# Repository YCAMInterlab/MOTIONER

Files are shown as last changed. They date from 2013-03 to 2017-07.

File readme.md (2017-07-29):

# MOTIONER

## Open source low cost inertial motion capture system.



MOTIONER is a low cost inertial motion capture system developed for Reactor for Awareness in Motion(RAM) project at Yamaguchi Center for Arts in Media (YCAM). Using MOTIONER, you can capture, record and playback body movements, and send the data via OSC messages over a network. MOTIONER is designed to work with RAM Dance Toolkit using openFrameworks, and will work with creative coding environments that provide OSC. MOTIONER is developed in collaboration with Yoko Ando (The Forsythe Company) and other dancers. MOTIONER is a light weight, low-stress, and low latency system. Because it's an inertial system, the sensors can be attached either inside or on the outside of clothing.

For more details, please see [MOTIONER wiki](https://github.com/YCAMInterlab/MOTIONER/wiki/)

詳しい情報は[MOTIONER wiki](https://github.com/YCAMInterlab/MOTIONER/wiki/)を参照してください。

## Licenses

### Application
MOTIONER software by YCAM InterLab and Yoshito Onishi is licensed under the 
[Apache License, Version2.0](http://www.apache.org/licenses/LICENSE-2.0.html)

    Copyright 2012-2013 YCAMInterLab and Yoshito Onishi

    Licensed under the Apache License, Version 2.0 (the "License");
    you may not use this file except in compliance with the License.
    You may obtain a copy of the License at

       http://www.apache.org/licenses/LICENSE-2.0

    Unless required by applicable law or agreed to in writing, software
    distributed under the License is distributed on an "AS IS" BASIS,
    WITHOUT WARRANTIES OR CONDITIONS OF ANY KIND, either express or implied.
    See the License for the specific language governing permissions and
    limitations under the License.

### Arduino, Processing sketch and mbed code

Copyright 2012-2013 YCAMInterLab and Yoshito Onishi

MOTIONER Arduino, Processing sketch and mbed code by YCAM InterLab and Yoshito Onishi are licensed under the 
[GNU GPL(General Public License) v3.0](http://www.gnu.org/licenses/gpl.html)

### Hardware

<br /><span xmlns:dct="http://purl.org/dc/terms/" property="dct:title">MOTIONER hardware related documents (Schematics, Eagle files, Solder Stencil Mask, Drawing of MOTIONER base, MOTIONER pcb board, vacuum case and strap)</span> by <a xmlns:cc="http://creativecommons.org/ns#" href="http://interlab.ycam.jp/projects/ram" property="cc:attributionName" rel="cc:attributionURL">YCAM InterLab, Yoshito Onishi</a> is licensed under a <a rel="license" href="http://creativecommons.org/licenses/by-sa/4.0/">Creative Commons Attribution-ShareAlike 4.0 International License</a>.

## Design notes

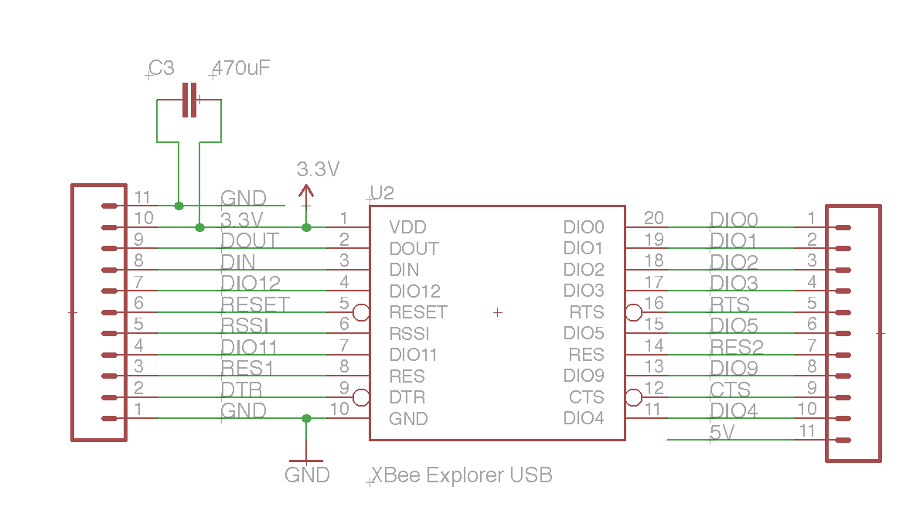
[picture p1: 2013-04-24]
circuit/schematics/xbee_explorer.png

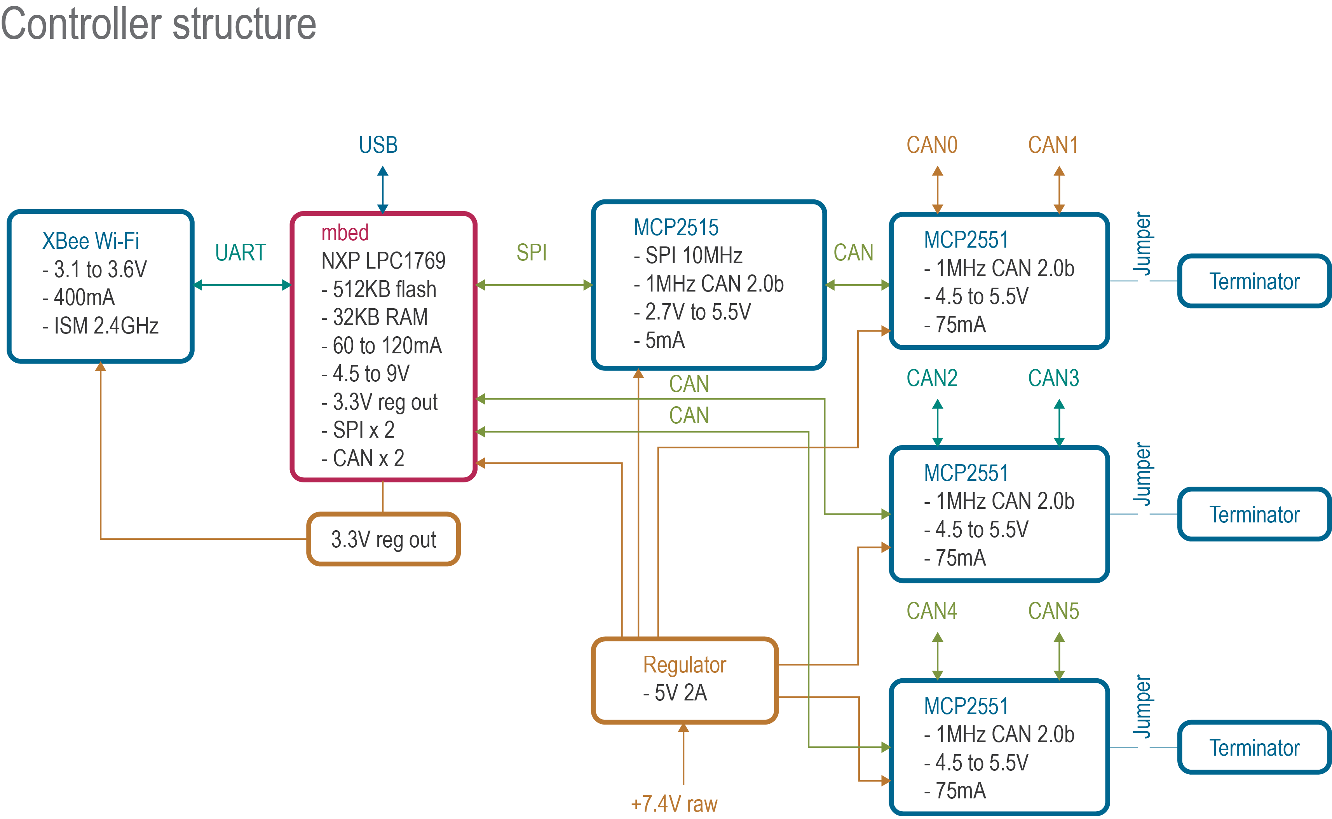
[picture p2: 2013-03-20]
documents/png/Controller-diagram.png

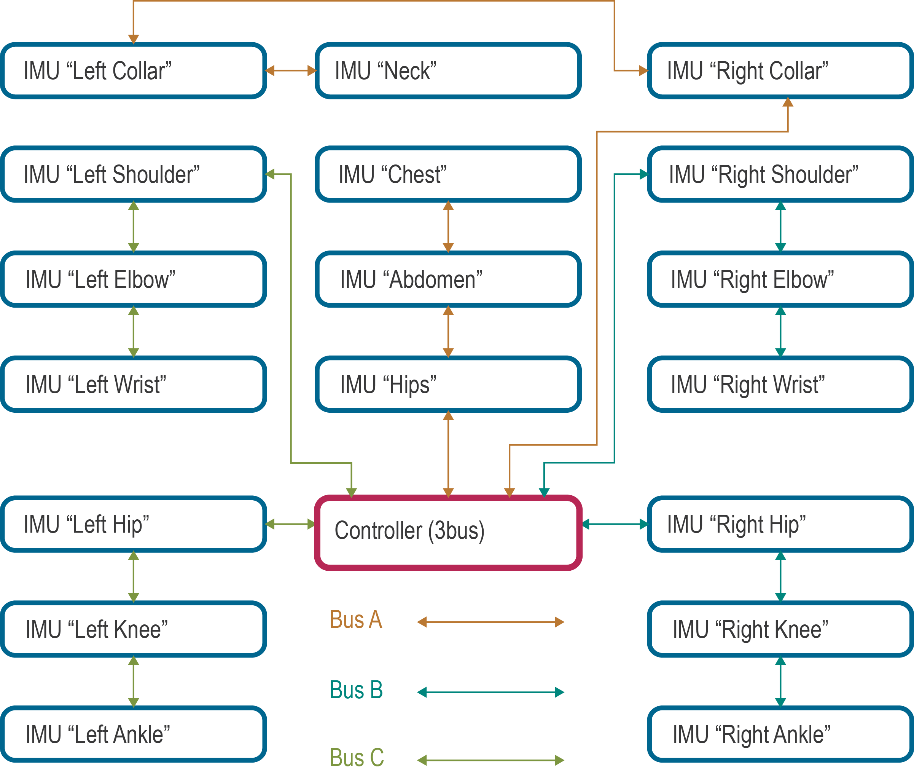
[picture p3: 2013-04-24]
documents/ai/CAN bus diagram.png

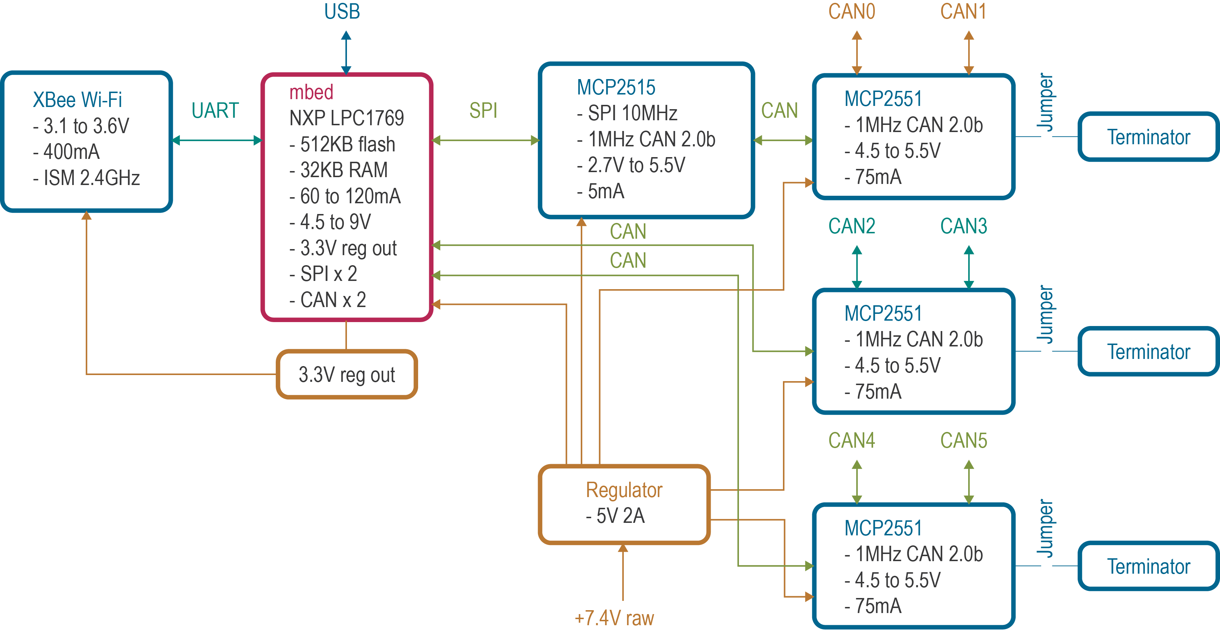
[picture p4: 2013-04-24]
documents/ai/Controller diagram.png

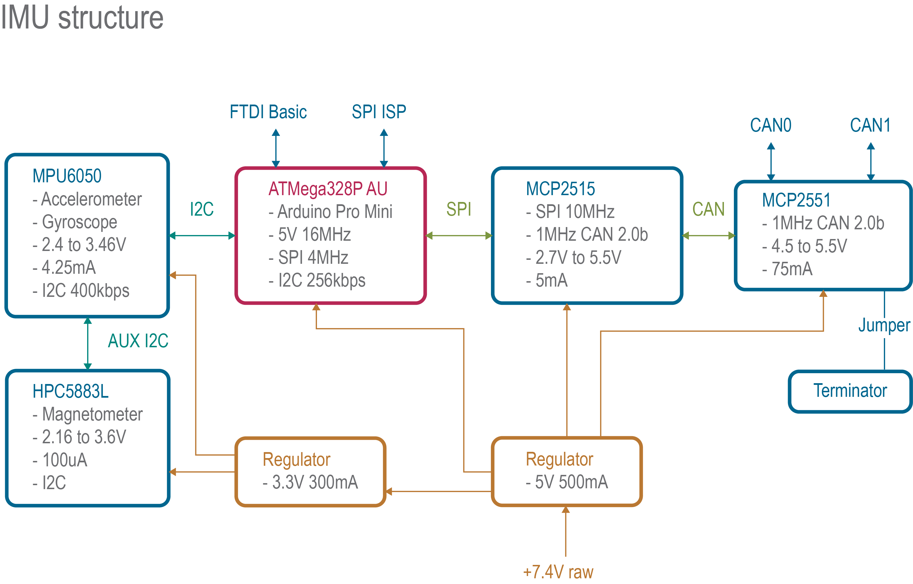
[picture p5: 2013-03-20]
documents/png/IMU-diagram.png

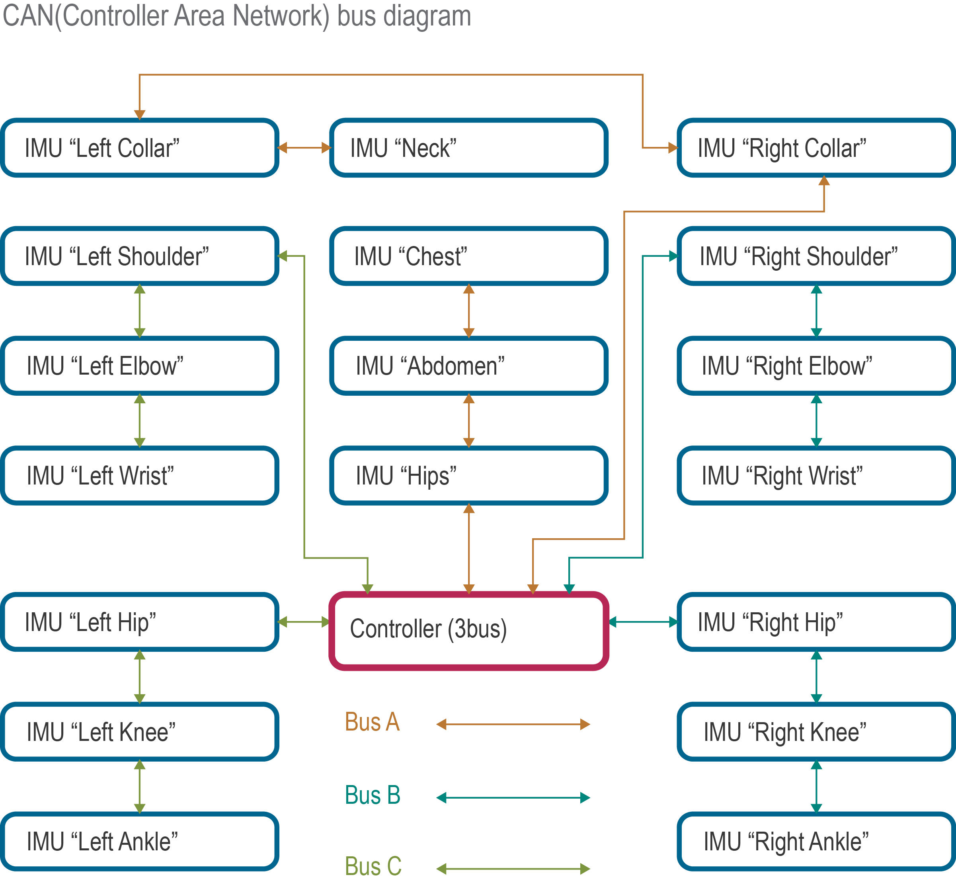
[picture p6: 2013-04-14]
documents/png/CAN-bus-diagram.png

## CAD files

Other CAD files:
circuit/stencil/dxf/MotionerNode-tcream.dxf

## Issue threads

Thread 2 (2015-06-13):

Things to fix in the wiki

jtragtenberg, 2015-06-13:
Hello,
I am making my Motioner sensors and I noticed some small mistakes in the wiki:

in the tutorial showing how to use the Arduino UNO as an ISP programmer, the frizzing image tells you have to put the capacitor between the 5V and the Reset... that is dangerous... it missed one hole, its between GND and Reset.

Another mistake is in the parts list, it says that for the IMU that the 10kOhm resistors are the R5-9, while they are only from R5 to R8.

And another thing I noticed is that the mbed code is the only one missing in the github. You only put the binary, and I really want to understand what is going on and maybe improve it a bit if I can. Can you please put it there?

One last thing: You added a calibration process in the making tutorial but forgot to put the referred folder in gitHub: "Open the MOTIONER/Arduino/calibration folder and open calibrationServo.ino"... there is no calibration folder there...

thanks a lot!
Amazing project!

I'm eager to contribute to it as much as I can!

jtragtenberg, 2015-06-13:
Another mistake in the parts:
C9 isn't a 0.1 uF capacitor as listed in the 0.1uF IMU parts list

itotaka, 2015-06-15:
> the frizzing image tells you have to put the capacitor between the 5V and the Reset... that is dangerous... it missed one hole, its between GND and Reset.

It's fixed. Thank you!

> Another mistake is in the parts list, it says that for the IMU that the 10kOhm resistors are the R5-9, while they are only from R5 to R8.

Fixed.

> And another thing I noticed is that the mbed code is the only one missing in the github. You only put the binary, and I really want to understand what is going on and maybe improve it a bit if I can. Can you please put it there?

Sorry, I'm checking this right now, wait for a bit.

> One last thing: You added a calibration process in the making tutorial but forgot to put the referred folder in gitHub: "Open the MOTIONER/Arduino/calibration folder and open calibrationServo.ino"... there is no calibration folder there...

Fixed, Please check here again.
https://github.com/YCAMInterlab/MOTIONER/wiki/Make-MOTIONER-IMU-and-Controller

> C9 isn't a 0.1 uF capacitor as listed in the 0.1uF IMU parts list

Fixed.

Thanks!!!!

jtragtenberg, 2015-06-15:
Thanks Takayuki!

just noticed one other thing: the controller battery connectors aren't in the buying list either.
I noticed you used in the picture two lipoly batteries and on the buying list you chose the 6 AA battery pack instead, but since I prefer the lipoly, I put the connectors there. The problem was that I put a 90˚ model of the connector, and the only way it fit was with the opposite polarity... Only after almost burning my board I read the eagle file and noticed the right polarity.
It would be nice to add to the parts list a straight jst connector and the barrel connectors too.

Thank you!

Here is a video of my first working IMU. Haven't calibrated them yet and is already very good!
https://youtu.be/LNvjPWxWtFw

I am planning on making an app for mapping the gestures from motioner to sound, I'll send you my updates!

jtragtenberg, 2015-06-15:
You could also put in the buying list the servo motor and mdf boards for calibration...
And you could put as an alternative to the Silhouete for cutting the solder stencils a laser cutter. I made mine with these and they have worked great!

itotaka, 2015-06-16:
Here's MOTIONER mbed code, the place will be changed.
For now, please use this mbed repository.

https://developer.mbed.org/users/FalconOnishi/code/MotionerController/

and yes, we chose 6AA battery pack when we published, since Lipo battery is sometimes a bit dangerous. But maybe it's good to add description for who wanna use it.

> Here is a video of my first working IMU. Haven't calibrated them yet and is already very good!

Thanks for sharing your video.
it's really good to see it's working at your place!!

> You could also put in the buying list the servo motor and mdf boards for calibration...
> And you could put as an alternative to the Silhouete for cutting the solder stencils a laser cutter. I made mine with these and they have worked great!

Great! We'd love to add these.
Thanks, it's very helpful!!

jtragtenberg, 2015-06-19:
One other thing, Ito
I just realized that one of the components isn't specified in the buying list. The XBee Wifi has two models, the S6 and a new version: S6B. I bought the second one and just realized from the picture that you used S6. They seem to be compatible, but I don't know if the mbed code has to change at all.
All the configurations from S6 configuration file can be set on the S6B. There are, though some 20 configuration items that are new in this version that don't seem to make much of a change.

Since my board isn't sending any OSC messages (I checked with the motioner app as well as with PureData and also with OSC data monitor) I don't know if the problem is in the Controller Board, in the mbed code or in the XBee itself. There seems to be something going a lot wrong since the voltage regulator and the CAN controller are heating up a lot! After some seconds the four mbed leds 1 and 4 start blinking alternately with the leds 2 and 3, which is a mbed code error alert. I checked the voltage in all the power elements, and the 5v for mbed and 3.3v for xbee are fine.

Since I've never used mbed or xbee wifi before its taking a lot to understend the mbed code, but I hope I find a way to fix this problem.

Can it be a problem that I'm using only one IMU sensor to test? Does the mbed code break if all the sensors aren't connected? That wouldn't make sense, and the code doesn't seem to have anything like that. I want to, at first, use only 3 IMUs to monitor just one arm, so I just bought enough components to make these 3. Hope I can make them work soon...

It would be nice to specify in the list you used XBee Wifi S6

Thank you!

XianWorld, 2015-10-23:
I have read all the three codes of IMU, Controller and Motion App, the message from IMU is include velocity and the control message is 'q':

```c++
void MotionerIMU::updateCAN()
{
    switch (getCANControlMessage()) {
    
        case 0: break; /// no message
    
        case 'q':
            //Serial.println("StartTransfer");
            digitalWrite(LED, HIGH);
            sendCANDataQuaternion();
            sendCANDataAux();
            digitalWrite(LED, LOW);
            break;
    
        default: break;
    }
}
```

But Controller only read the quaternion and send it to Motioner App:

```c++
                // 0to18 Joints and RX buffer*2(quaternion xy or zw) and 8 byte CAN data
                if (nodeId < N_JOINTS && slot < 2 && msg.len == 8) {
                    //gPc.printf("%x, %x\n\r", nodeId, slot);

                    for (int q=0; q<2; q++) { //quaternion x, y or z, w
                        for (int f=0; f<4; f++) { //float byte 0 - 4
                            //[node id][quaternion x, y or z, w][float bytes 0 - 4]
                            gTmpQuat[nodeId][q+slot*2].b[f] = msg.data[f+q*4];
                        }
                    }
                }
```
And I don't understand why did you add the position vector to the data length, but not send anything of it:

```C++
#define N_JOINTS (18)
#define DATA_LEN (4*4*N_JOINTS+3*4+4) //18*quaternion*float bytes + position vector*flot bytes + delimiter
```
```C++
void updateXBeeWiFi()
{
    IPv4TransmitRequest data;

    //XBee WiFi Transmit
    //IPv4TransmitRequest data;
    //int len = 2*4*18+2*3; //18*quaternion+3*vector q // short
    //int len = 4*4*18+4*3; //18*quaternion+3*vector // float
    //int len = 8; //18*quaternion+3*vector // float
    //char buf[len];

    // debug
    //for (int i=0; i<len; i++)
    //buf[i] = (char)('0'+i%70);

    for (int i=0; i<N_JOINTS; i++) {
        if (gReceived[i][0] && gReceived[i][1]) {
            for (int j=0; j<4; j++) {
                __gQuat__[i][j] = gTmpQuat[i][j].f;
            }
        }
    }

    uint8_t *buf = (uint8_t *)__gQuat__;

    buf[DATA_LEN-4] = (char)'a';
    buf[DATA_LEN-3] = (char)'b';
    buf[DATA_LEN-2] = (char)'c';
    buf[DATA_LEN-1] = (char)'d';

    IpAddr addr(192, 168, 2, 1);
    data.setAddress(addr);
    data.setDstPort(9750);
    data.setSrcPort(9750);
    data.setProtocol(PROTOCOL_UDP);
    //data.setPayload((uint8_t*)buf);
    //data.setPayloadLength(strlen(buf));
    data.setPayload(buf);
    data.setPayloadLength(DATA_LEN);
    data.setFrameId(gXBee.getNextFrameId());//0
    gXBee.send(data);

    //gPc.printf("len:%d\r\n",strlen(buf));
    const int r = gXBee.getWiResponse(TX_STATUS_RESPONSE, data.getFrameId());

    /// error
    if (r==-1) {
        gPc.printf("Fatal error! XBee WiFi didn't responce!\r\nTrying to reset modem again.");
        if (initXBeeWiFi(20)) {
            gPc.printf("Failure...");
            error("");
        } else {
            gPc.printf("succeed\r\n");
        }
    }
}
```

And the CAN control message send from Controller to IMU is 'b' and 'e', not 'q':

```C++
void beginTransmitQuaternion()
{
    sendCanMessage('b');
    for (int i=0; i<N_MBED_CAN; i++)
        sendMbedCanMessage(i, 'b');
}

//--------------------------------------------------------------
void endTransmitQuaternion()
{
    sendCanMessage('e');
    for (int i=0; i<N_MBED_CAN; i++)
        sendMbedCanMessage(i, 'e');
}
```

And the Motioner App read velocity from the message sent from Controller:

```C++
    const int    FLOAT_BYTES = 4;
    const int    QUATERNION_DIM = 4;
    const int    IMU_DATA_DIM = 5;
    const int    UDP_MESSAGE_LENGTH = IMU_DATA_DIM*FLOAT_BYTES*(NUM_JOINTS-N_END_SITE)+4;
    const string UDP_PACKET_DELIMITER = "abcd";
```

```C++
            for (int j=0; j<IMU_DATA_DIM; j++) { /// quaternion xyzw + velocity
                for (int k=0; k<FLOAT_BYTES; k++) { /// float bytes
                    /// i*4*5 + i*4 + k
                    const int idx =
                    (i-nEndSite)*IMU_DATA_DIM*FLOAT_BYTES + j*FLOAT_BYTES+k;
                    mData[i][j].b[k] = udpMessage[idx];
                }
                //if (ofGetFrameNum()%60==0)
                //    cout << mData[i][j].f << ",";
            }
            //if (ofGetFrameNum()%60==0)
            //    cout << endl;

            /// get velocity
            if (mData[i][4].f!=0.0f) {
                //cout << i << ":" << mData[i][4].f << endl;
                frame.velocity.at(i) = mData[i][4].f;
            }
```

According to all above, I judge that [the code of Controller from mbed](https://developer.mbed.org/users/FalconOnishi/code/MotionerController/) is old(or testing) version.

Please check it, thank you.

We are making the Motioner system according to your way, and now debug each parts together.

XianWorld, 2015-10-25:
The Controller code is old version, would you pls upload new version.

Thx a lot.

gongyuzhen, 2017-02-09:
The new version？

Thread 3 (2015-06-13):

Improving the IMU board

jtragtenberg, 2015-06-13:
The soldering pads for the HMC5883L are too small. I would make it as long outside of the chip just a little bit like the ones from MPU6050, that way it is easier to check if all the pads were correctly soldered, and it makes it possible to fix the soldering with a soldering iron.

I can improve it, how do I upload to this git my changes?

kylemcdonald, 2015-06-22:
since you've forked the repository, once you make the changes to the file you can do this:

```
$ git add -u # this stages changes to any files already added to git
$ git commit -m "made the soldering pads for the HMC5883L bigger" # this saves any staged changes
$ git push origin master # this sends your commit to the server
```

then on github there will be a button that appears that allows you to make a pull request, and we can merge it.

jtragtenberg, 2015-07-21:
Thanks Kyle,
Just learned how to use eagle and git to do this, just requested a pull.

kylemcdonald, 2015-07-23:
closed by #7

Closed 2015-07-23.

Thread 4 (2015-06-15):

How did you get position?

jtragtenberg, 2015-06-15:
I am reading you code and still I couldn't figure out how you managed to get the position on stage from the actors using only joint angles...
Do you use any other external sensors like cameras or a kinect?

thanks!

itotaka, 2015-06-16:
No, sorry, currently MOTIONER doesn't get absolute positions of joints, body.
Once we tried to combine a camera or Kinects with it, but still need some developments..

jtragtenberg, 2015-06-16:
Then how did you do the videos you published where the avatars move around in space?
All the videos you have that happens, and is only possible if you have the position captured. If you got just relative positions the avatar would move as if it was in a slippery floor, no?

itotaka, 2015-06-16:
There're 2 possibilities.

1. We borrowed an optical motion capture system for experiments. Some of the videos and sample data are from them.
2. MOTIONER application simulates walking roughly by fixing the lowest joint position. The data from MOTIONER sensors itself is, yes, slippery on the floor.

mmmmm, I'm sorry for your confusion, I'll add the description about this.

jtragtenberg, 2015-06-16:
Great, that was what I was looking for.
I beleive videos like https://vimeo.com/61942488 show the dancers reacting with each other wearing motioners, so its probably the second alternative.
Is this lowest joint position fixing done in RAM Dance Toolkit? The OSC data sent from the mbed is only the quaternions of each joint?

And I sent you an email to taka@ycam.jp, is that your email?
beacause I'm researching on my masters how to create music from dance, and my plans are to use motioner to generate music. I would like to know more about the RAM project, and about YCAM for my research.
could I send you some questions about the process?
Could you pass me the email of the other people involved in this project so I could interview them too?

my email is tragtenberg@gmail.com

Thank you!

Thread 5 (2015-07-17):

WIFI setting and network problems

sworldy, 2015-07-17:
Hi all,

  You guys' work is very amazing. I am also attempting to build a device just like that in the tutorial.
    I use Xbee S6B wifi module and have encountered the network connection problem, as a result, I cant see the unfixed Skeleton. I set up all the 18 imu motioners and 1 controller just like the demo shown. And all the settings are correct as shown in the tutorial. I am wondering the reasons for the connection error, whether setting up the wrong communication protocol or the software/code problem.
   I also tried to connect XBee to PC through gateway. However, the data received from wifi S6b was just something like FF 00 E8 FF which was obviously wrong.
   Based on my understanding, I would like to ask you guys some questions.

1.	From the tutorial, the IP address for PC or motioner application is 192.168.2.1; controller IP address is 192.168.2.103; the wifi S6 module IP address is 192.168.2.7 and the destination IP address is 192.168.2.1; the motioner application target IP address is 192.168.2.103.
My puzzle is about the connection between wifi S6 / S6B and PC application. From the user manual, one’s MY is set to be the DL of another and another’s MY is referred to one’s DL. My question is the target IP setting of the motioner application, the target IP address is referred to the controller IP address instead of the wifi S6 module IP. Is the data sent out by wifi S6/S6B module with controller IP address as the destination address for motioner application?
 2.  In the application gui xml file, Device Incoming UDP Port means UDP protocol used while the wifi S6 configuration, IP setting is TCP protocol. My question is whether these two protocols are compatible to be used together?
3.  In XBee WiFi_setting file, ID SSID name is set as "f" while the network created in the tutorial, the SSID name is named as "MotionerNet". Are these two SSID names supposed to be the same? If not, how will XBee identify the network?

If anything wrong, please do not hesitate to correct me.
Please help me clear my doubts. Thank you guys in advance.

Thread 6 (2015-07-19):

Problems in Magnetometer Calibration

jtragtenberg, 2015-07-19:
Hello,
I have just bought the servo and cut the wood to calibrate my IMUs.
My calibration went fine with the accelerometer and gyroscope (I hope so), at least I could visualize the colored lines and dots move as I moved my IMU. The problem was when I started calibrating the magnetometer. I had it all set up with the servo but when I ran the processing sketch the green dot didn't leave the center of the sphere. And I tried to upload this only-dotted-calibration-data to my motioner IMU and it failed with this message:

It seems like a bug in the sketch.
Can someone help me?

java.lang.RuntimeException: java.lang.RuntimeException: Eigenvalue Decomposition failed
	at com.jogamp.common.util.awt.AWTEDTExecutor.invoke(AWTEDTExecutor.java:58)
	at jogamp.opengl.awt.AWTThreadingPlugin.invokeOnOpenGLThread(AWTThreadingPlugin.java:103)
	at jogamp.opengl.ThreadingImpl.invokeOnOpenGLThread(ThreadingImpl.java:206)
	at javax.media.opengl.Threading.invokeOnOpenGLThread(Threading.java:172)
	at javax.media.opengl.Threading.invoke(Threading.java:191)
	at javax.media.opengl.awt.GLCanvas.display(GLCanvas.java:541)
	at processing.opengl.PJOGL.requestDraw(PJOGL.java:688)
	at processing.opengl.PGraphicsOpenGL.requestDraw(PGraphicsOpenGL.java:1651)
	at processing.core.PApplet.run(PApplet.java:2256)
	at java.lang.Thread.run(Thread.java:745)
Caused by: java.lang.RuntimeException: Eigenvalue Decomposition failed
	at org.ejml.simple.SimpleEVD.<init>(Unknown Source)
	at org.ejml.simple.SimpleBase.eig(Unknown Source)
	at MagnCalibration.outputMagnCalibration(MagnCalibration.java:430)
	at MagnCalibration.keyPressed(MagnCalibration.java:300)
	at processing.core.PApplet.keyPressed(PApplet.java:3510)
	at processing.core.PApplet.handleKeyEvent(PApplet.java:3328)
	at processing.core.PApplet.dequeueEvents(PApplet.java:2728)
	at processing.core.PApplet.handleDraw(PApplet.java:2397)
	at processing.opengl.PJOGL$PGLListener.display(PJOGL.java:862)
	at jogamp.opengl.GLDrawableHelper.displayImpl(GLDrawableHelper.java:665)
	at jogamp.opengl.GLDrawableHelper.display(GLDrawableHelper.java:649)
	at javax.media.opengl.awt.GLCanvas$10.run(GLCanvas.java:1289)
	at jogamp.opengl.GLDrawableHelper.invokeGLImpl(GLDrawableHelper.java:1119)
	at jogamp.opengl.GLDrawableHelper.invokeGL(GLDrawableHelper.java:994)
	at javax.media.opengl.awt.GLCanvas$11.run(GLCanvas.java:1300)
	at java.awt.event.InvocationEvent.dispatch(InvocationEvent.java:302)
	at java.awt.EventQueue.dispatchEventImpl(EventQueue.java:733)
	at java.awt.EventQueue.access$200(EventQueue.java:103)
	at java.awt.EventQueue$3.run(EventQueue.java:694)
	at java.awt.EventQueue$3.run(EventQueue.java:692)
	at java.security.AccessController.doPrivileged(Native Method)
	at java.security.ProtectionDomain$1.doIntersectionPrivilege(ProtectionDomain.java:76)
	at java.awt.EventQueue.dispatchEvent(EventQueue.java:703)
	at java.awt.EventDispatchThread.pumpOneEventForFilters(EventDispatchThread.java:242)
	at java.awt.EventDispatchThread.pumpEventsForFilter(EventDispatchThread.java:161)
	at java.awt.EventDispatchThread.pumpEventsForHierarchy(EventDispatchThread.java:150)
	at java.awt.EventDispatchThread.pumpEvents(EventDispatchThread.java:146)
	at java.awt.EventDispatchThread.pumpEvents(EventDispatchThread.java:138)
	at java.awt.EventDispatchThread.run(EventDispatchThread.java:91)

jtragtenberg, 2015-07-19:
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

here is what I saw in the MagnCalibration sketch

jtragtenberg, 2015-07-19:
And just to check, are these images ok for the accelerometer and gyroscope calibration?

It is said on the wiki that there would be some examples of good calibration I believe you forgot to upload it.

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

jtragtenberg, 2015-07-19:
It seems it was a problem with the hardware itself...
I have just calibrated the magnetometer of another board and it seems perfect:
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

jtragtenberg, 2015-07-19:
I tried swapping the magnetometer in the board, desoldered the last one and soldered a new one. But the RAW data kept coming with null values for magnetometer readings. from the 9 numbers that come one after the other the 3 accelerometer and 3 gyroscope values are fine. Just the magnetometer values keep coming with zeros...

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

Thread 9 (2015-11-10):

Bug in the calcQuaternion algorithm

jtragtenberg, 2015-11-10:
Hi there,
I've been all this time learning C++ and figuring out how the Motioner and RazorIMU libraries work.
I make my own prototyping board with just an arduino UNO soldered with a HMC8553L magnetometer and MPU6050 gyro+accel. I'm doing all my tests connecting the board through USB.
I made a code out of the Motioner.ino where in the loop() I just added the lines:

  float qx = motioner.mRazorIMU.getQuatX();
  float qy = motioner.mRazorIMU.getQuatY();
  float qz = motioner.mRazorIMU.getQuatZ();
  float qw = motioner.mRazorIMU.getQuatW();

  Serial.print(qw);
  Serial.print('|');
  Serial.print(qx);
  Serial.print('|');
  Serial.print(qy);
  Serial.print('|');
  Serial.println(qz);

where the getQuat* functions I added are just:

    float getQuatX() const { return quat.x; }
    float getQuatY() const { return quat.y; }
    float getQuatZ() const { return quat.z; }
    float getQuatW() const { return quat.w; }

and I made the mRazorIMU object public on the Motioner class.

Out of this I noticed a bug in the angles as I tilt them, where the quaternions change sign for no reason...
I have calibrated my board with the IMUDebug.ino firmware and it all worked well in the IMUvisualization Processing sketch.

Does anyone know why this bug keeps bugging me?
Is this discontinuity and sign inversion expected?

thank you

jtragtenberg, 2015-11-19:
Anyone?...

jtragtenberg, 2015-11-19:
Has anyone an example of a Motioner IMU working just outputting the quaternion values ?
It really seems to me that the bug is in the calcQuaternion algorithm, the Gamasutra code that transforms the Matrix into quats....

skistua, 2015-12-15:
you are right . It's wrong. Give me your email address . then I send your  right one . it's project is long gone. Here is no one answer your question.

jtragtenberg, 2015-12-15:
Hi there,

 its joao@batebit.cc

Thank you

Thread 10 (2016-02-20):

jxx_315 questions

jtragtenberg, 2016-02-20:
jxx_315 has sent me an email asking these things:

hi, my friend:
   I am an electronics enthusiast, recently in the understanding of motion capture projects. A few days ago I saw your message in MOTIONER project. I would like to know what is wrong wtih the code, can  you give me the correct code? thanks.
I have several questions:
1. "How did you get position?" This seems to be a serious problem, you have any good way to get position?
2: The Controller code is old version, do you have new version?

jtragtenberg, 2016-02-20:
Hey jxx_315, I'll answer you here:

1: to get a position from an inertial motion capture you have to work hard (; The IMU sensors only give you orientation values, that is, angles! With this angles and estimating the size of each body limb you can organize many vectors and estimate the position in relation to the persons body center. To get an estimation of the position of someone walking you have to fix the lower part of the body... complicated huh? I heard there is also an algorithm to help predicting displacement in jump, but I haven't got a clue how that is done...

2: The controller code is in mbed, do you have it? They didn't put it the source on github, its only in the mbed platform. The link to it is: https://developer.mbed.org/users/FalconOnishi/code/MotionerController/

What have you managed to do so far?

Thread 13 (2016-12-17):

How to select electronic components in the project

mobilemajia, 2016-12-17:
Dear Takayuki,

Good day! The motioner project is a great well designed project :) I am an electronic fan and I learnt this project is a happy journey!

I found a problem when I tried to start building the project. It seems that some electronic components obsolete when I want to buy them. One of them is "XBee Wi-Fi" in the buying list in the following links:

888-XB24-WFPIT-001:
http://www.mouser.jp/ProductDetail/Digi-International/XB24-WFPIT-001/?qs=sGAEpiMZZMtbbFRYSpBbW17OwPV%252b3FUq

It is not available now. Do you know where to buy it? Or is there another choice?

I find two alternative components is alike it, but I don't know how to choose the right one. I don't know which component will be good for motioner. Could you please help me to choose one? If it is good, do I need to change the code in order to adapt to the new electronic components? Thank you so much.

The main difference among these two components with the original one is the "data rate", "interface type", "aerial connector type".

Two alternative components:

888-XB2B-WFPS-001:
http://www.mouser.cn/Search/ProductDetail.aspx?qs=NnxJOTDiCpMA4dfbwsXxnw%3d%3d

888-XB2B-WFST-001
http://www.mouser.cn/Search/ProductDetail.aspx?qs=NnxJOTDiCpM4EnkS2FAtgw%3d%3d

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

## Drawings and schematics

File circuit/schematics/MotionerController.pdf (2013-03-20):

VREF 5 | GND VCC
VREF 5 | GND VCC

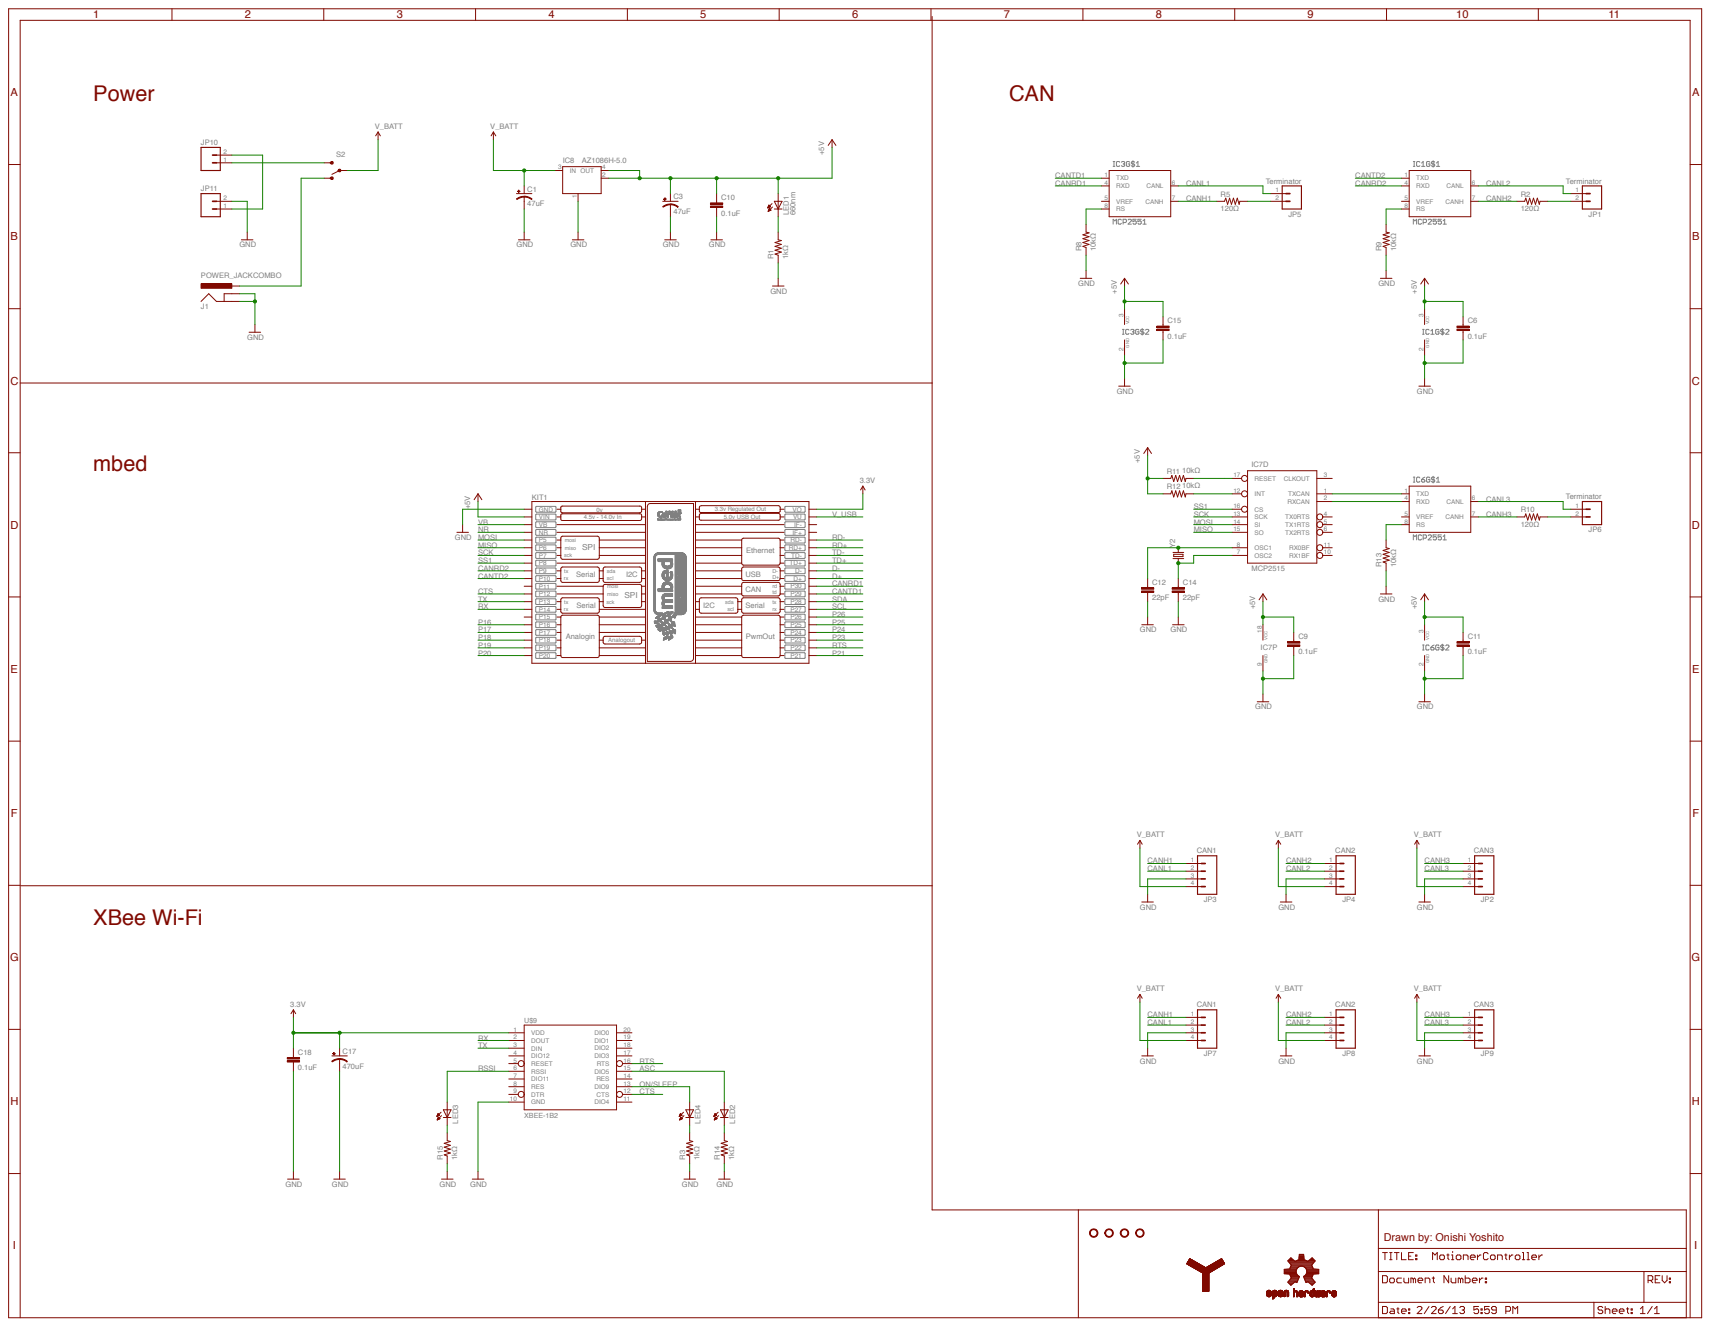
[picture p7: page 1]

Drawn by: Onishi Yoshito

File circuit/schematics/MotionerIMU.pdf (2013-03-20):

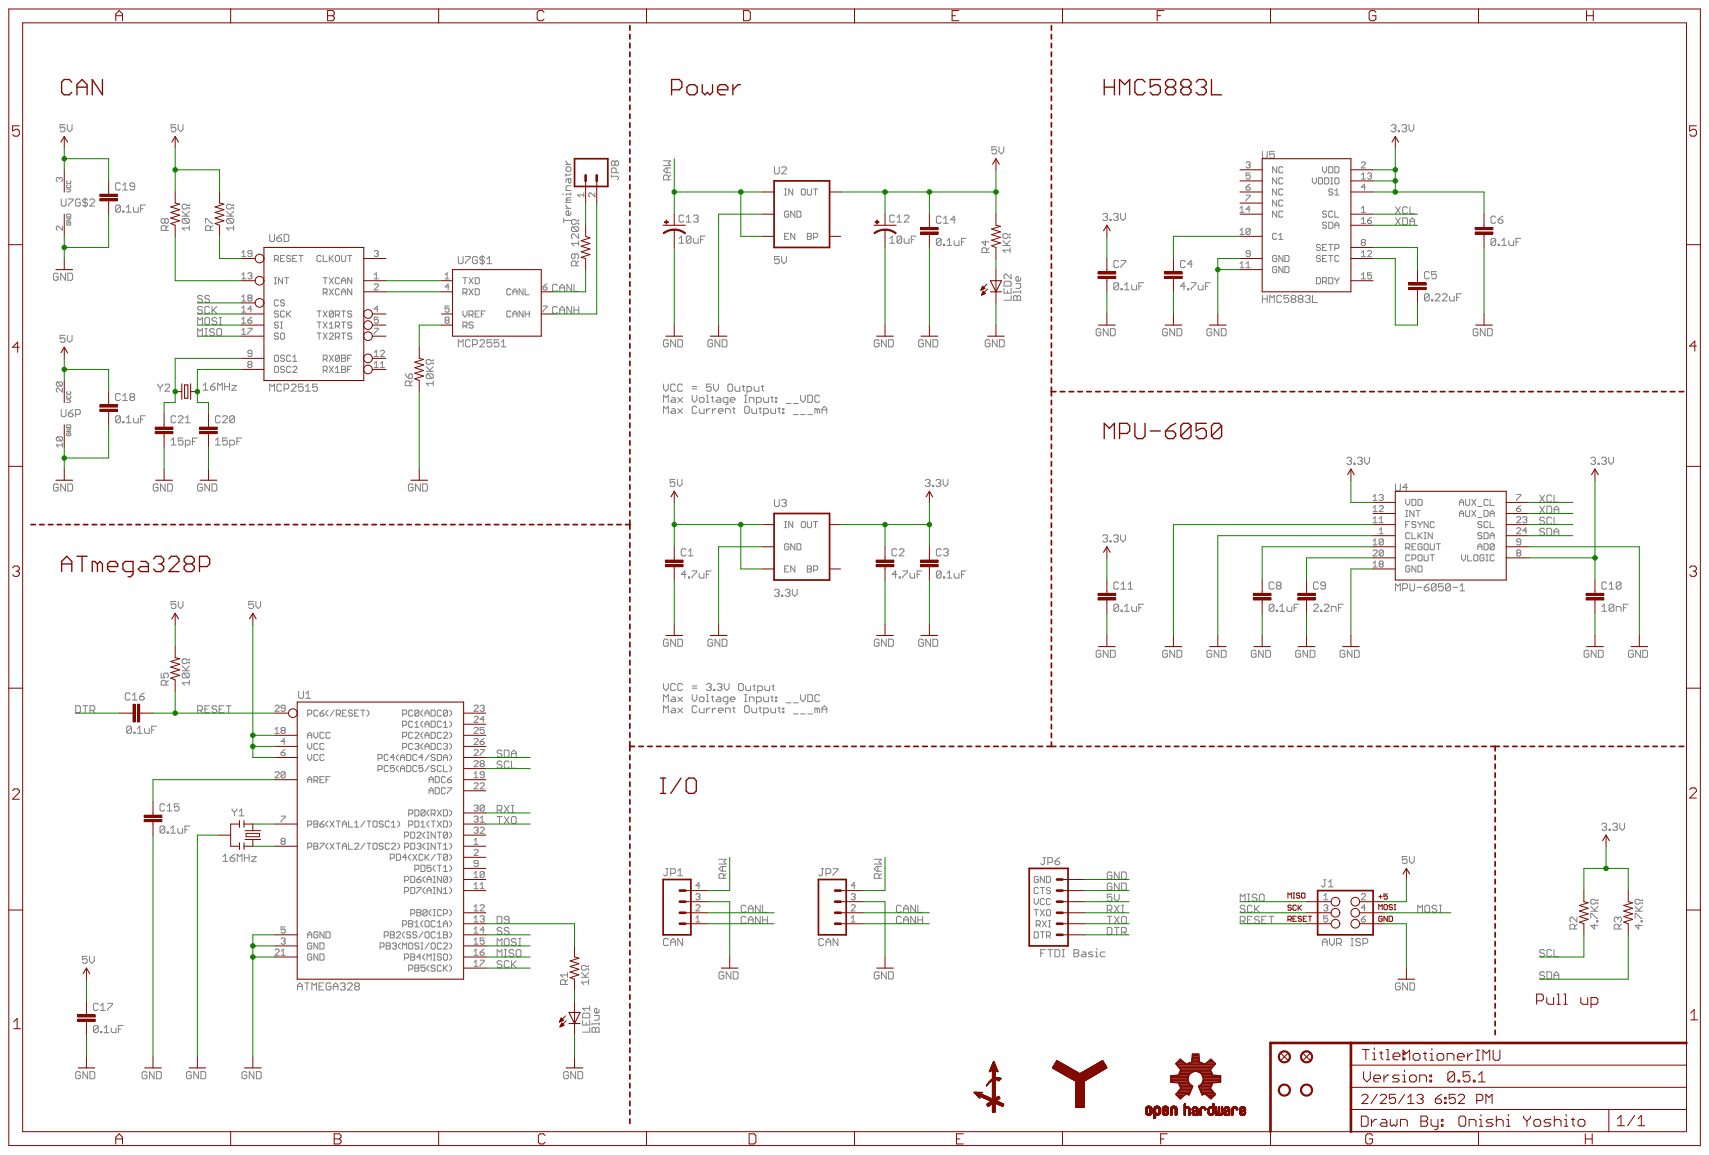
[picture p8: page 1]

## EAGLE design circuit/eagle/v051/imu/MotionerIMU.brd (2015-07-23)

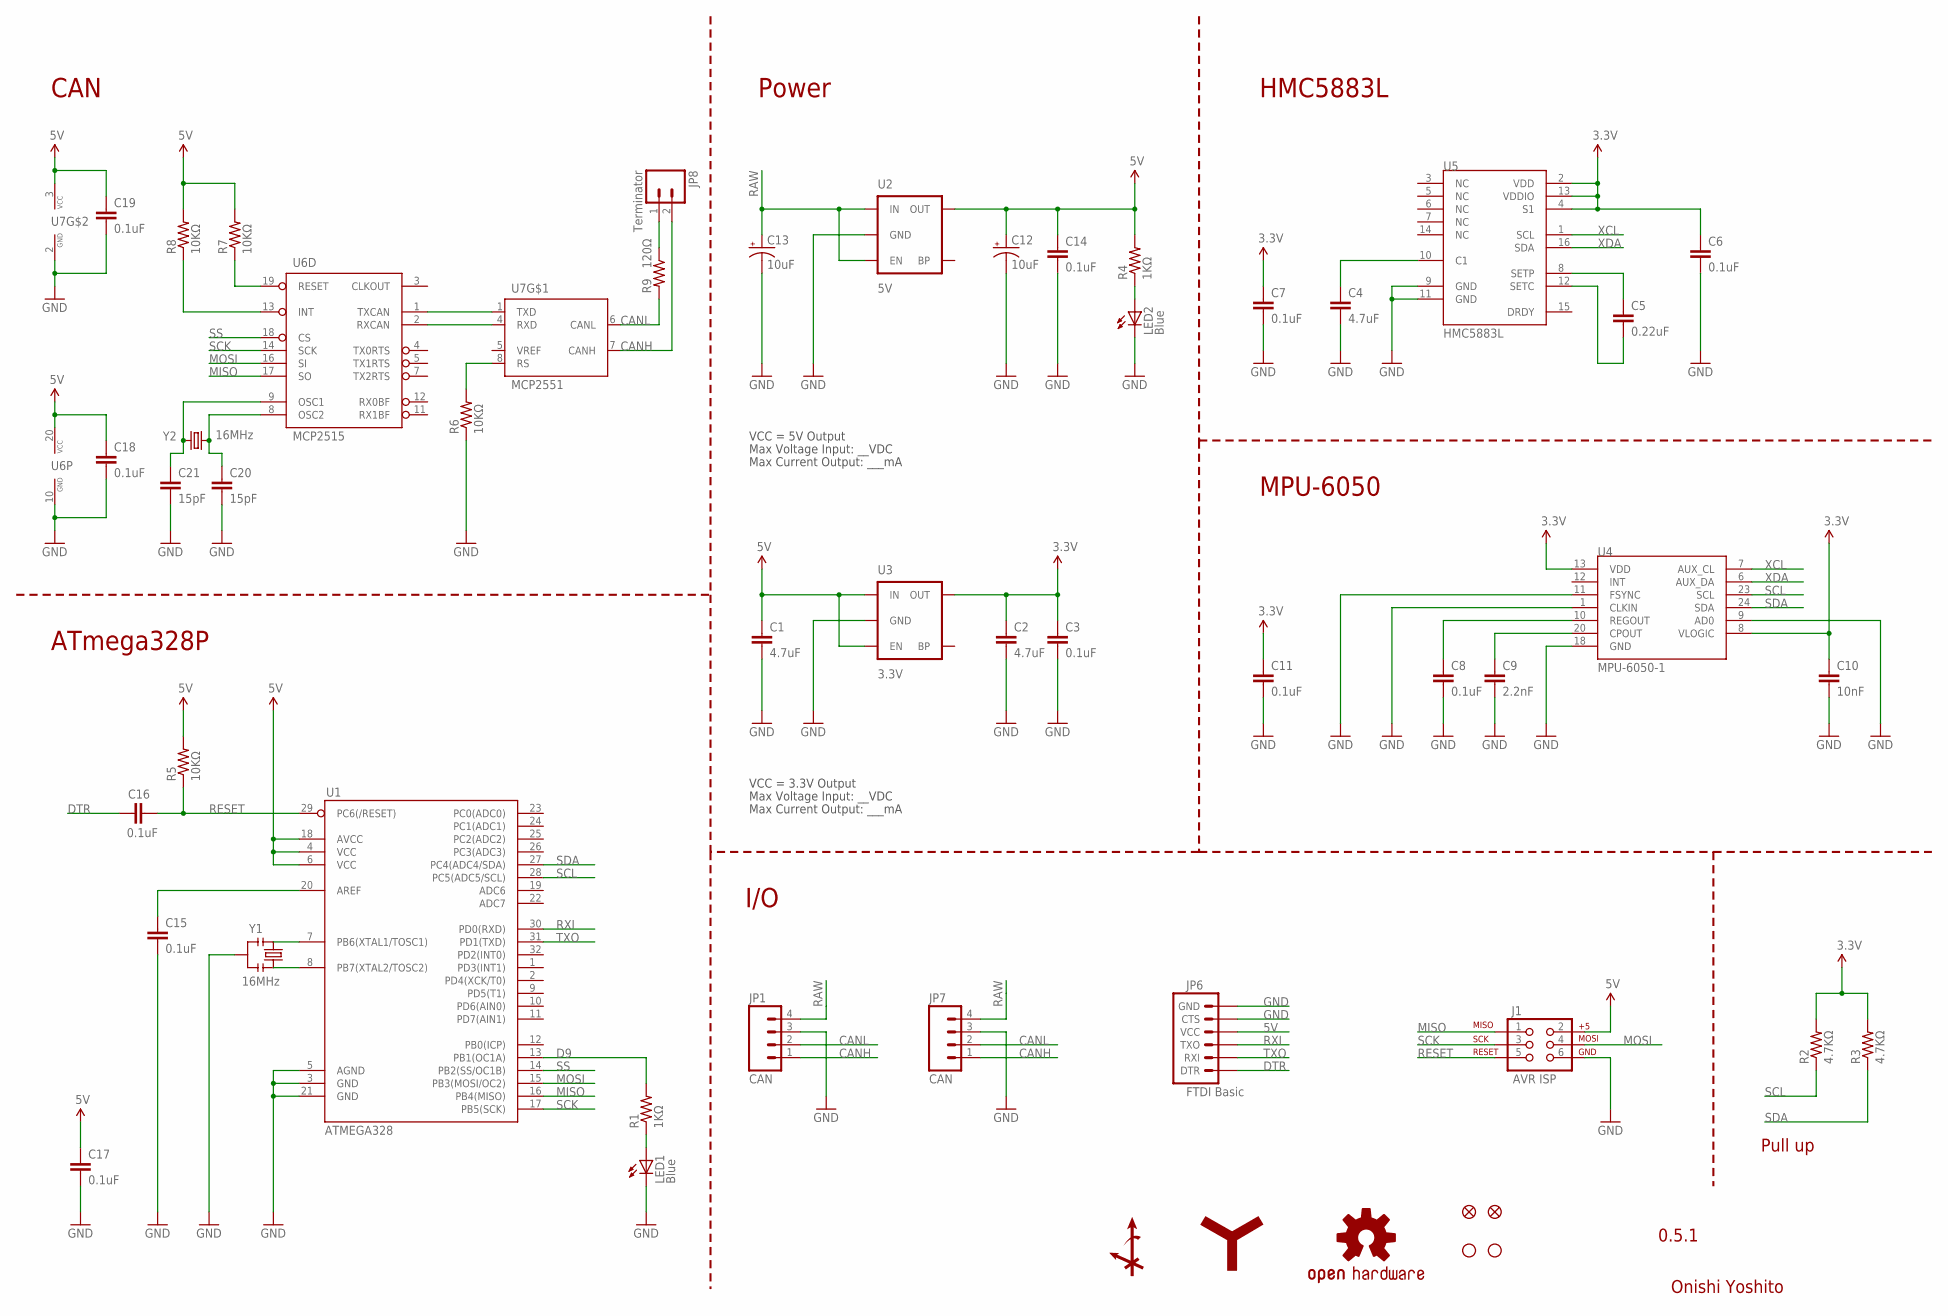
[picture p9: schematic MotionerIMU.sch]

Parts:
C1, C2, C4: 4.7uF; 0402-CAP
C3, C6, C7, C8, C11, C14, C15, C16, C17, C18, C19: 0.1uF; 0402-CAP
C5: 0.22uF; 0402-CAP
C9: 2.2nF; 0402-CAP
C10: 10nF; 0402-CAP
C12, C13: 10uF; EIA3216
C20, C21: 15pF; 0402-CAP
J1: AVR ISP; 2X3-NS
JP1, JP7: CAN; JST-4-PTH
JP2, JP5: FIDUCIALUFIDUCIAL; MICRO-FIDUCIAL
JP3, JP4: STAND-OFFTIGHT; STAND-OFF-TIGHT
JP6: FTDI Basic; 1X06
JP8: Terminator; 1X02
LED1, LED2: Blue; LED-0603
R1, R4: 1KΩ; 0402-RES
R2, R3: 4.7KΩ; 0402-RES
R5, R6, R7, R8: 10KΩ; 0402-RES
R9: 120Ω; 0402-RES
U1: ATMEGA328; TQFP32-08
U2: 5V; SOT23-5
U3: 3.3V; SOT23-5
U4: MPU-6050-1; QFN-24-4MM2
U5: HMC5883L; 16LPCC
U6: MCP2515; TSSOP20
U7: MCP2551; SO08
U$2: OSHW-LOGOS; OSHW-LOGO-S
U$11: AXIS-ANGLE_S
U$13: YCAM_LOGO_L
Y1: 16MHz; RESONATOR-SMD
Y2: 16MHz; CRYSTAL-SMD-5X3

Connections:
3.3V: C2.1, C3.1, C6.1, C7.1, C10.1, C11.1, R2.2, R3.2, U3.5 (OUT), U4.8 (VLOGIC), U4.13 (VDD), U5.2 (VDD), U5.4 (S1), U5.13 (VDDIO)
5V: C1.1, C12.A (+), C14.1, C17.1, C18.1, C19.1, J1.2, JP6.4 (VCC), R4.2, R5.2, R7.2, R8.2, U1.4 (VCC), U1.6 (VCC), U1.18 (AVCC), U2.5 (OUT), U3.1 (IN), U3.3 (EN), U6.20 (VCC), U7.3 (VCC)
CANH: JP1.1, JP7.1, JP8.2, U7.7 (CANH)
CANL: JP1.2, JP7.2, R9.2, U7.6 (CANL)
D9: R1.2, U1.13 (PB1(OC1A))
DTR: C16.1, JP6.1 (DTR)
GND: C1.2, C2.2, C3.2, C4.2, C6.2, C7.2, C8.2, C9.2, C10.2, C11.2, C12.C (-), C13.C (-), C14.2, C15.2, C17.2, C18.2, C19.2, C20.2, C21.2, J1.6, JP1.3, JP6.5 (CTS), JP6.6 (GND), JP7.3, LED1.C, LED2.C, R6.1, U1.3 (GND), U1.5 (AGND), U1.21 (GND), U2.2 (GND), U3.2 (GND), U4.1 (CLKIN), U4.9 (AD0), U4.11 (FSYNC), U4.18 (GND), U5.9 (GND), U5.11 (GND), U6.10 (GND), U7.2 (GND), Y1.2
MISO: J1.1, U1.16 (PB4(MISO)), U6.17 (SO)
MOSI: J1.4, U1.15 (PB3(MOSI/OC2)), U6.16 (SI)
unnamed: LED1.A, R1.1
unnamed: LED2.A, R4.1
unnamed: C4.1, U5.10 (C1)
unnamed: C5.1, U5.8 (SETP)
unnamed: C5.2, U5.12 (SETC)
unnamed: C9.1, U4.20 (CPOUT)
unnamed: C8.1, U4.10 (REGOUT)
unnamed: U1.7 (PB6(XTAL1/TOSC1)), Y1.1
unnamed: U1.8 (PB7(XTAL2/TOSC2)), Y1.3
unnamed: C15.1, U1.20 (AREF)
unnamed: U6.1 (TXCAN), U7.1 (TXD)
unnamed: U6.2 (RXCAN), U7.4 (RXD)
unnamed: R6.2, U7.8 (RS)
unnamed: R7.1, U6.19 (RESET)
unnamed: R8.1, U6.13 (INT)
unnamed: C20.1, U6.8 (OSC2), Y2.3 (2)
unnamed: C21.1, U6.9 (OSC1), Y2.1
unnamed: JP8.1, R9.1
RAW: C13.A (+), JP1.4, JP7.4, U2.1 (IN), U2.3 (EN)
RESET: C16.2, J1.5, R5.1, U1.29 (PC6(/RESET))
RXI: JP6.3 (TXO), U1.30 (PD0(RXD))
SCK: J1.3, U1.17 (PB5(SCK)), U6.14 (SCK)
SCL: R2.1, U1.28 (PC5(ADC5/SCL)), U4.23 (SCL)
SDA: R3.1, U1.27 (PC4(ADC4/SDA)), U4.24 (SDA)
SS: U1.14 (PB2(SS/OC1B)), U6.18 (CS)
TXO: JP6.2 (RXI), U1.31 (PD1(TXD))
XCL: U4.7 (AUX_CL), U5.1 (SCL)
XDA: U4.6 (AUX_DA), U5.16 (SDA)

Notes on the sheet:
Onishi Yoshito
0.5.1
HMC5883L
MPU-6050
Pull up
Max Voltage Input: __VDC
Max Current Output: ___mA
VCC = 3.3V Output
VCC = 5V Output
ATmega328P
Power
CAN
I/O

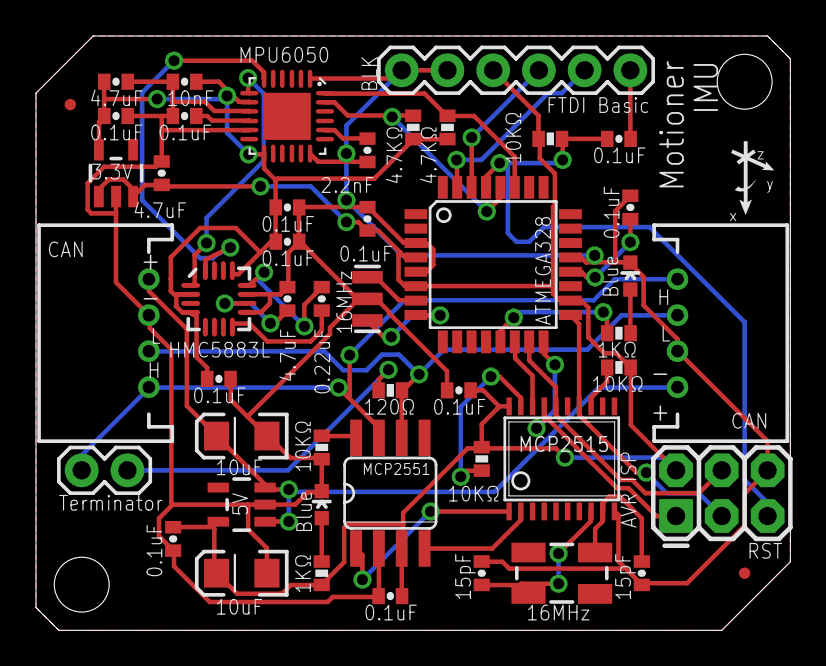
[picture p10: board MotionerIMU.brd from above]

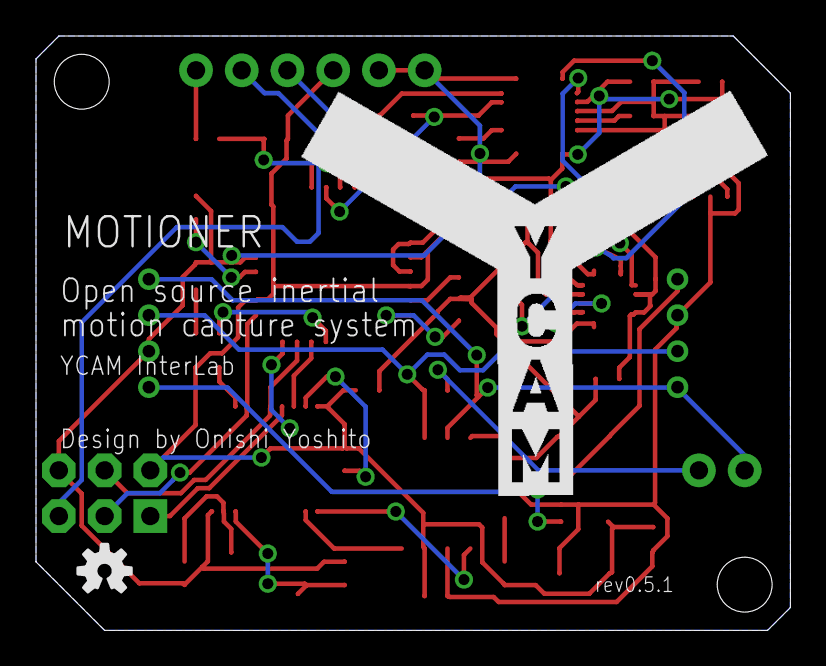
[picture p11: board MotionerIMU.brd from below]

Board: 2 copper layers, 41.9 x 33.0 mm, 53 parts (2 on the bottom side), 37 nets.

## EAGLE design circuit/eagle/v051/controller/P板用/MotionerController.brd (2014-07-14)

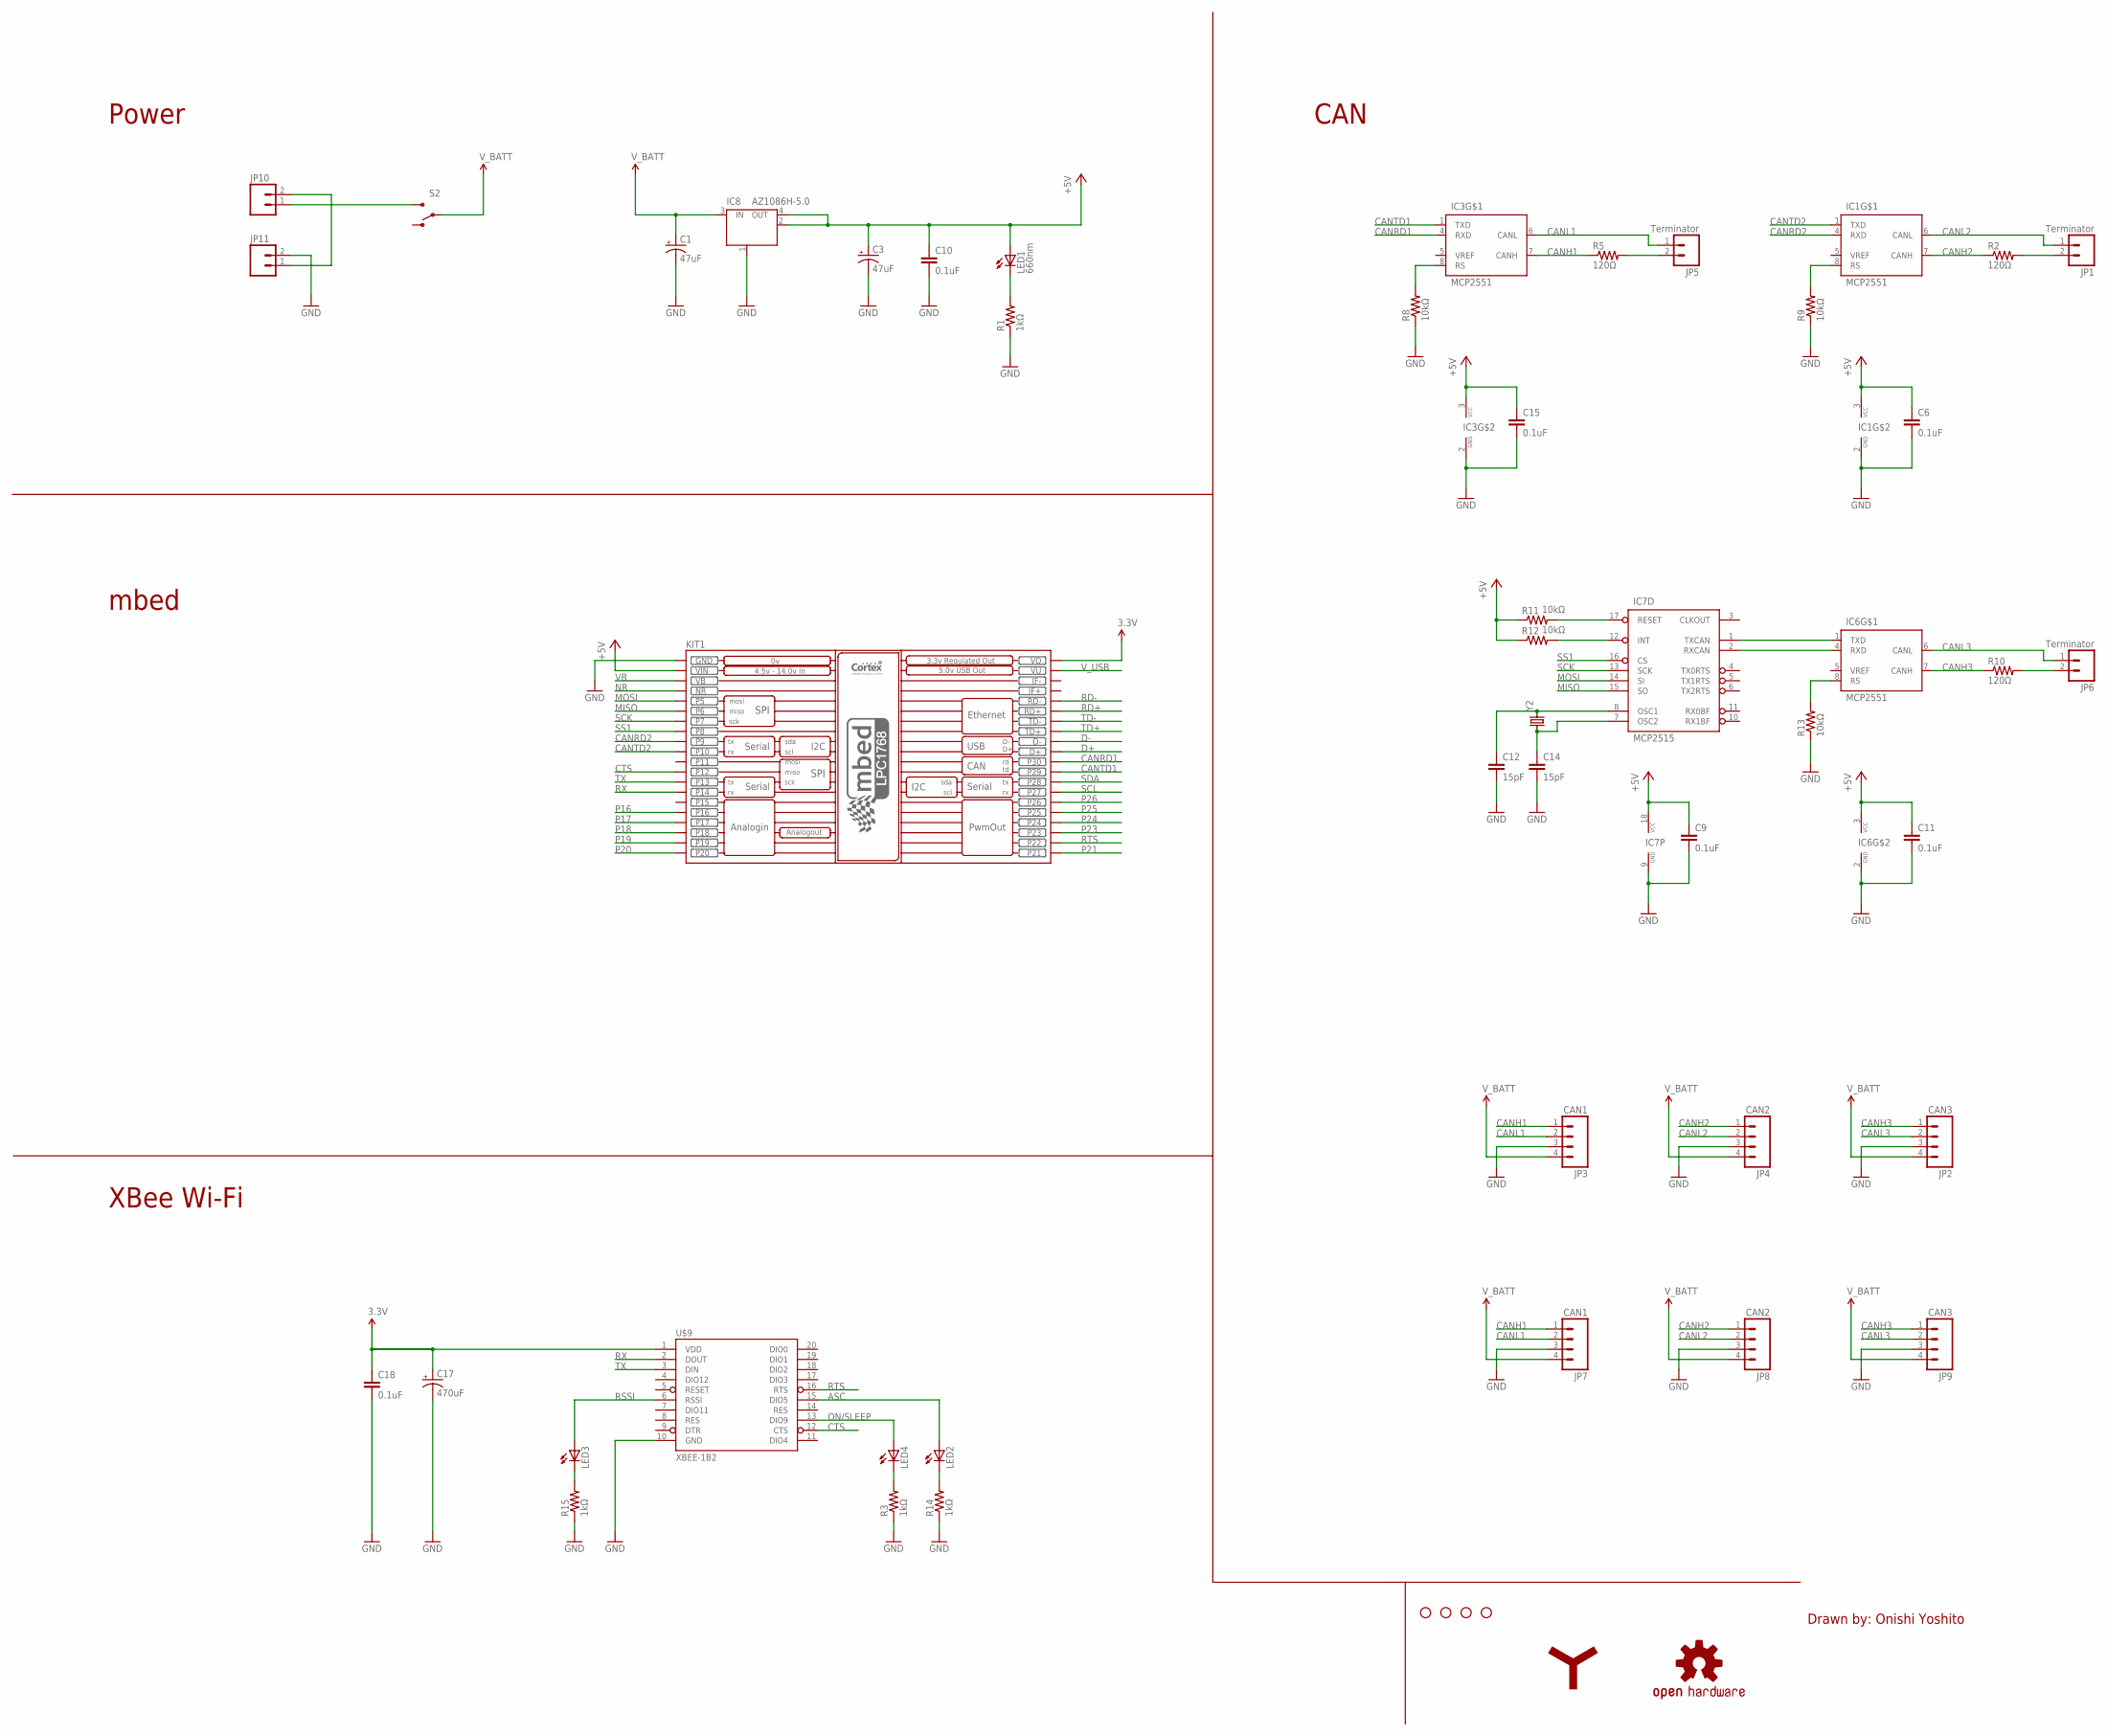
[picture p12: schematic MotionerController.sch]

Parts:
C1, C3: 47uF; PANASONIC_D
C6, C9, C10, C11, C15, C18: 0.1uF; 0603-CAP
C12, C14: 15pF; 0603-CAP
C17: 470uF; PANASONIC_G
IC1, IC3, IC6: MCP2551; SO08
IC7: MCP2515; SO-18W
IC8: AZ1086H-5.0; SOT223
JP1, JP5, JP6: Terminator; 1X02
JP2, JP9: CAN3; JST-4-PTH
JP3, JP7: CAN1; JST-4-PTH
JP4, JP8: CAN2; JST-4-PTH
JP10, JP11: M02JST-PTH-2; JST-2-PTH
JP12, JP13, JP15, JP16: STAND-OFF
KIT1: MBED_NXP_LPC1768; MBED-KIT
LED1: 660nm; LED-0603
LED2, LED3, LED4: LED0603; LED-0603
R1, R3, R14, R15: 1kΩ; 0603-RES
R2, R5, R10: 120Ω; 0603-RES
R8, R9, R11, R12, R13: 10kΩ; 0603-RES
S2: SWITCH-SPDTPTH; SWITCH-SPDT
U$9: XBEE-1B2; XBEE-SILK
U$10: YCAM_LOGO_L
U$12: OSHW-LOGOL; OSHW-LOGO-L
Y2: CRYSTAL5X3; CRYSTAL-SMD-5X3

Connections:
3.3V: C17.+, C18.1, KIT1.VOUT (VO), U$9.1 (VDD)
7.4V: C1.+, IC8.3 (IN), JP2.4, JP3.4, JP4.4, JP7.4, JP8.4, JP9.4, S2.2
+5V: C3.+, C6.1, C9.1, C10.1, C11.1, C15.1, IC1.3 (VCC), IC3.3 (VCC), IC6.3 (VCC), IC7.18 (VCC), IC8.2 (OUT), IC8.4 (OUT), KIT1.VIN, LED1.A, R11.1, R12.1
ASC: LED2.A, U$9.15 (DIO5)
CANH1: IC3.7 (CANH), JP3.1, JP7.1, R5.1
CANH2: IC1.7 (CANH), JP4.1, JP8.1, R2.1
CANH3: IC6.7 (CANH), JP2.1, JP9.1, R10.1
CANL1: IC3.6 (CANL), JP3.2, JP5.1, JP7.2
CANL2: IC1.6 (CANL), JP1.1, JP4.2, JP8.2
CANL3: IC6.6 (CANL), JP2.2, JP6.1, JP9.2
CANRD1: IC3.4 (RXD), KIT1.P$30 (P30)
CANRD2: IC1.4 (RXD), KIT1.P$9 (P9)
CANTD1: IC3.1 (TXD), KIT1.P$29 (P29)
CANTD2: IC1.1 (TXD), KIT1.P$10 (P10)
CTS: KIT1.P$12 (P12), U$9.12 (CTS)
D+: KIT1.D+
D-: KIT1.D-
GND: C1.-, C3.-, C6.2, C9.2, C10.2, C11.2, C12.2, C14.2, C15.2, C17.-, C18.2, IC1.2 (GND), IC3.2 (GND), IC6.2 (GND), IC7.9 (GND), IC8.1 (GND/ADJ), JP2.3, JP3.3, JP4.3, JP7.3, JP8.3, JP9.3, JP11.2, KIT1.GND, R1.1, R3.1, R8.1, R9.1, R13.1, R14.1, R15.1, U$9.10 (GND)
MISO: IC7.15 (SO), KIT1.P$6 (P6)
MOSI: IC7.14 (SI), KIT1.P$5 (P5)
unnamed: LED1.C, R1.2
unnamed: LED4.C, R3.2
unnamed: JP10.1, S2.3 (S)
unnamed: IC3.8 (RS), R8.2
unnamed: IC1.8 (RS), R9.2
unnamed: JP1.2, R2.2
unnamed: IC6.1 (TXD), IC7.1 (TXCAN)
unnamed: IC6.4 (RXD), IC7.2 (RXCAN)
unnamed: IC7.12 (INT), R12.2
unnamed: JP5.2, R5.2
unnamed: IC7.17 (RESET), R11.2
unnamed: IC6.8 (RS), R13.2
unnamed: JP6.2, R10.2
unnamed: C12.1, IC7.8 (OSC1), Y2.3 (2)
unnamed: C14.1, IC7.7 (OSC2), Y2.1
unnamed: JP10.2, JP11.1
unnamed: LED3.C, R15.2
unnamed: LED2.C, R14.2
NR: KIT1.NR
ON/SLEEP: LED4.A, U$9.13 (DIO9)
P16: KIT1.P$16 (P16)
P17: KIT1.P$17 (P17)
P18: KIT1.P$18 (P18)
P19: KIT1.P$19 (P19)
P20: KIT1.P$20 (P20)
P21: KIT1.P$21 (P21)
P23: KIT1.P$23 (P23)
P24: KIT1.P$24 (P24)
P25: KIT1.P$25 (P25)
P26: KIT1.P$26 (P26)
RD+: KIT1.RD+
RD-: KIT1.RD-
RSSI: LED3.A, U$9.6 (RSSI)
RTS: KIT1.P$22 (P22), U$9.16 (RTS)
RX: KIT1.P$14 (P14), U$9.2 (DOUT)
SCK: IC7.13 (SCK), KIT1.P$7 (P7)
SCL: KIT1.P$27 (P27)
SDA: KIT1.P$28 (P28)
SS1: IC7.16 (CS), KIT1.P$8 (P8)
TD+: KIT1.TD+
TD-: KIT1.TD-
TX: KIT1.P$13 (P13), U$9.3 (DIN)
VB: KIT1.VB
V_USB: KIT1.VU

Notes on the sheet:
CAN
Power
mbed
XBee Wi-Fi
Drawn by: Onishi Yoshito

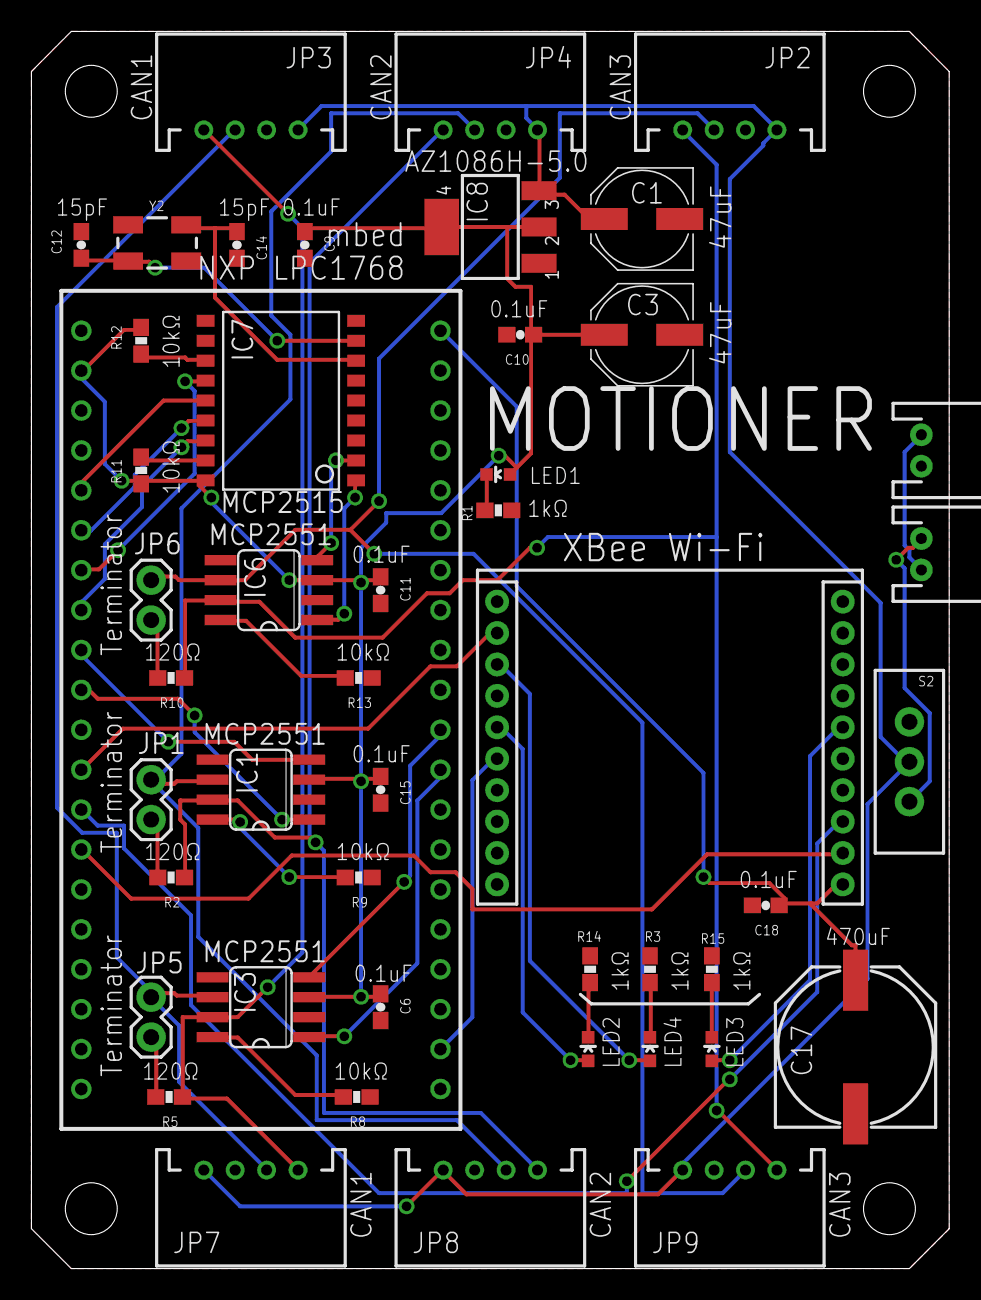
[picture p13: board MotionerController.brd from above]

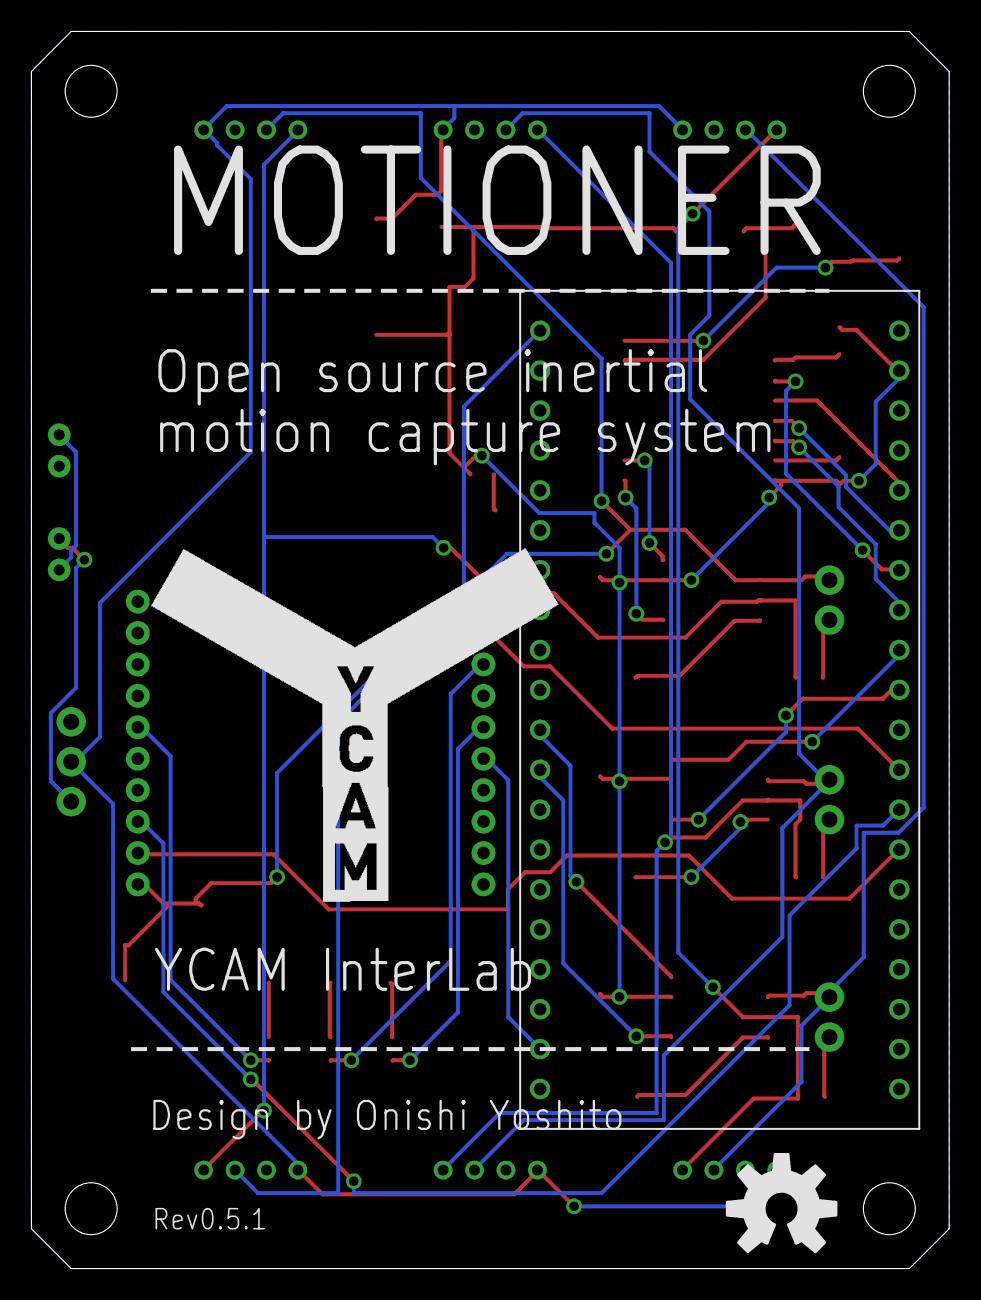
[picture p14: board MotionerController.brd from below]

Board: 2 copper layers, 58.4 x 78.7 mm, 53 parts (2 on the bottom side), 43 nets.

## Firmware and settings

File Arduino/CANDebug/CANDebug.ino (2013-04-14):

///
/// MotionerLED and Serial debug
///
/// Developed by Onishi Yoshito
///
/// Copyright Onishi Yoshito and YCAM InterLab all rights reserved
/// This Arduino sketch is published under the __________
/// 

#include "SPI.h"
#include "CAN.h"

#include "CANLoopBackTest.h"
CANLoopBackTest canLoopBackTest;

static const long BAUDRATE = 57600;

void setup()
{
  Serial.begin(BAUDRATE);
    
  Serial.println("-- MotionerIMU CAN loopback test --"); 
  canLoopBackTest.setup();
}


void loop()
{
  canLoopBackTest.update();
}

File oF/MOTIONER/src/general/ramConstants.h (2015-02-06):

//
//  ramConstants.h
//  MOTIONER
//
//  Created by Onishi Yoshito on 12/4/12.
//
//

#ifndef MOTIONER_ramConstants_h
#define MOTIONER_ramConstants_h

#include "ofMain.h"
#include "ofxXmlSettings.h"

#define RAM_SINGLETON_CLASS

namespace ram {
    
    //------------------------------------------------------------------------------------
    
    /// skeleton joints
    //--------------------
    enum JointType {
		JOINT_HIPS              = 0,
		JOINT_ABDOMEN           = 1,//o
		JOINT_CHEST             = 2,
		JOINT_NECK              = 3,
		JOINT_HEAD              = 4, /// end site
        
		JOINT_LEFT_HIP          = 5,
		JOINT_LEFT_KNEE         = 6,
		JOINT_LEFT_ANKLE        = 7,//o
		JOINT_LEFT_TOE          = 8, /// end site
        
		JOINT_RIGHT_HIP         = 9,
		JOINT_RIGHT_KNEE        = 10,
		JOINT_RIGHT_ANKLE       = 11,//o
		JOINT_RIGHT_TOE         = 12, /// end site
        
		JOINT_LEFT_COLLAR       = 13,
		JOINT_LEFT_SHOULDER     = 14,
		JOINT_LEFT_ELBOW        = 15,
		JOINT_LEFT_WRIST        = 16,//o
		JOINT_LEFT_HAND         = 17, /// end site
        
		JOINT_RIGHT_COLLAR      = 18,
		JOINT_RIGHT_SHOULDER    = 19,
		JOINT_RIGHT_ELBOW       = 20,
		JOINT_RIGHT_WRIST       = 21,//o
		JOINT_RIGHT_HAND        = 22, /// end site
        
		NUM_JOINTS              = 23,
	};
    
    extern const int N_END_SITE;
    extern const int END_SITE[];
    
    //------------------------------------------------------------------------------------
    
    /// record and playback
    //--------------------
    enum CoderType {
        CODER_BINARY    = 0,
        CODER_BVH       = 1,
        //NUM_CODER_TYPES,
    };
    
    //------------------------------------------------------------------------------------
    
    /// Pre allocated data length for UDP packet
    //--------------------
    extern const int    UDP_PACKET_BUFFER;
    /// XBee WiFi message size via UDP
    /// float*quat*joints + float*position + delimiter
    /// 4*4*18 + 3*4 + 4
    extern const int    UDP_MESSAGE_LENGTH;
    extern const string UDP_PACKET_DELIMITER;
    extern const int    UDP_REFRESH_RATE;
    extern const double DEVICE_TIMEOUT_DUR;
    
    //--------------------
    extern const int    FLOAT_BYTES;
    extern const int    QUATERNION_DIM;
    extern const int    IMU_DATA_DIM;
    
    //--------------------
    extern const int    DEBUG_OSC_INCOMING_PORT;
    
    //--------------------
    //extern const string SETTINGS_XML;
    
    //------------------------------------------------------------------------------------
    extern const string GUI_XML;
    extern const string INSPECTOR_XML;
    extern const string GUI_FONT;
    
    //--------------------
    extern const string SKELETON_XML_DIR;
    
    //--------------------
    extern const string DEFAULT_SKELETON_SETTINGS;
    
    //--------------------
    extern const ofLogLevel DEFAULT_LOG_LEVEL;
    
    //------------------------------------------------------------------------------------
    extern const int LOGGER_INDENT;
    extern const int LOGGER_DEFAULT_BUFFER_SIZE;
    
    //------------------------------------------------------------------------------------
    extern const string MOTION_DATA_EXT;
    extern const string MOTION_DATA_DIR;
    extern const string MOTION_DATA_VERSION;
    extern const float MOTION_DATA_DEFAULT_FRAME_TIME;
    
    /// for file name for motions
    //--------------------
    extern const string TIME_STAMP_FORMAT;
    extern const string FILE_NAME_WILDCARD;
    
    //------------------------------------------------------------------------------------
    extern const int COLOR_H;
    extern const int COLOR_MH;
    extern const int COLOR_M;
    extern const int COLOR_ML;
    extern const int COLOR_L;
    extern const int COLOR_BG;
    extern const int COLOR_HILIGHT;
    
    //------------------------------------------------------------------------------------
    extern const string OSC_ADDR_RDT_PLAYER;
    extern const string OSC_ADDR_CALIBRATION;
    extern const string OSC_ADDR_RESET_POSITION;
    extern const string OSC_ADDR_SAVE_SKELETON;
    extern const string OSC_ADDR_REC_START;
    extern const string OSC_ADDR_REC_STOP;
    extern const string OSC_ADDR_EXTERNAL_POSITION;
    extern const string OSC_ADDR_CIRCLE_TRACKING_COMBINED;
    extern const string OSC_ADDR_CIRCLE_TRACKING_FILTERD;
    
    extern const float kJointErrorEpsilon;
    extern const float kJointErrorThreshould;
    
}

//----------------------------------------------------------------------------------------
namespace std {
	using namespace tr1; /// std::tr1:: as std::
}

#endif

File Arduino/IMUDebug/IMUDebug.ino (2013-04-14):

#include "CAN.h"
#include "vec3.h"
#include "EEPROM.h"
#include "Wire.h"
#include "SPI.h"
#include "I2Cdev.h"
#include "MPU60X0.h"
#include "RazorIMU.h"

RazorIMU razor;


void setup()
{
  Serial.begin(57600);
  Serial.println("-- extended RazorAHRS debug --");
  razor.setup();
}

void loop()
{
  // Read incoming control messages
  if (Serial.available() >= 2) {
      // Start of new RazorIMU control message
      if (Serial.read() == '#') {
          /// read serial again internally
          razor.updateSerial(Serial.read());
      }
  }
  razor.updateAHRS();
}

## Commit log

2013-03-20 added circuit and some resources
    [MotionerController.brd, MotionerController.sch, MotionerIMU.brd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]
2013-04-14 Added Arduino sketches and libraries
2014-07-14 Load free node structure from XML file
    [MotionerController.brd, MotionerController.sch, MotionerIMU.brd]
2014-12-19 fix position, external input for absolute position
    [ramConstants.h]
2015-02-04 Removed camera control tool
2015-02-04 Changed grid looks, removed show joint name func
2015-02-05 Updated disable joints
2015-02-06 Changed UI letters to Upper camel case
2015-07-21 made longer soldering pads for the HMC5883L
    [MotionerIMU.brd]

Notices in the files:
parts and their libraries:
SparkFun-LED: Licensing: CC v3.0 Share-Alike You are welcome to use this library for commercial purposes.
